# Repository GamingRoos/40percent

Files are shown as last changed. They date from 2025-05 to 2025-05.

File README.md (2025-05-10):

# THIS IS A WORK IN PROGRESS

I'm designing a 40% keyboard just for the fun of it and to learn how to make everything from scratch.  

There should be every required file in Git Repository for you to build your own, I'll also include the bill of materials for both KiCad/JLCPCB and also DigiKey if you wish to solder it all by hand.  

Here a few of the features of the board:

> - USB-C Support (USB2.0 for easy compatibility)
> - ATMEGA32U4 Microcontroller (Easily available and ready firmware support through QMK)
> - Live keymapping through QMK/VIAL
> - Gasket Mounting (Gummy O-Ring)
> - MOSTLY screwless Design (Excluding the four to mount the daughterboard)    
I'll think of more later    

What does the board conceptually look like?  

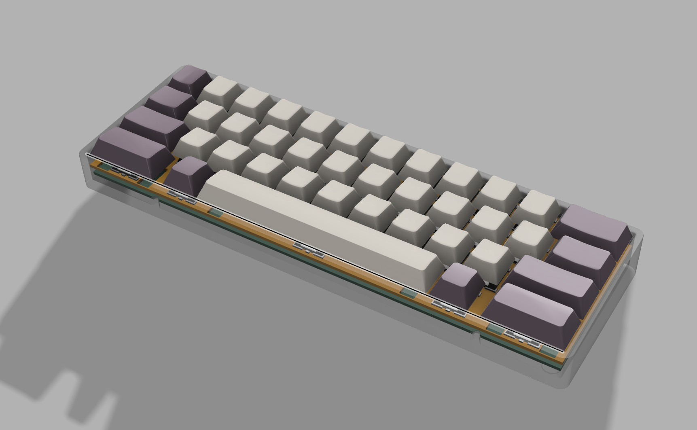
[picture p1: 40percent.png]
3D model/render of the keyboard

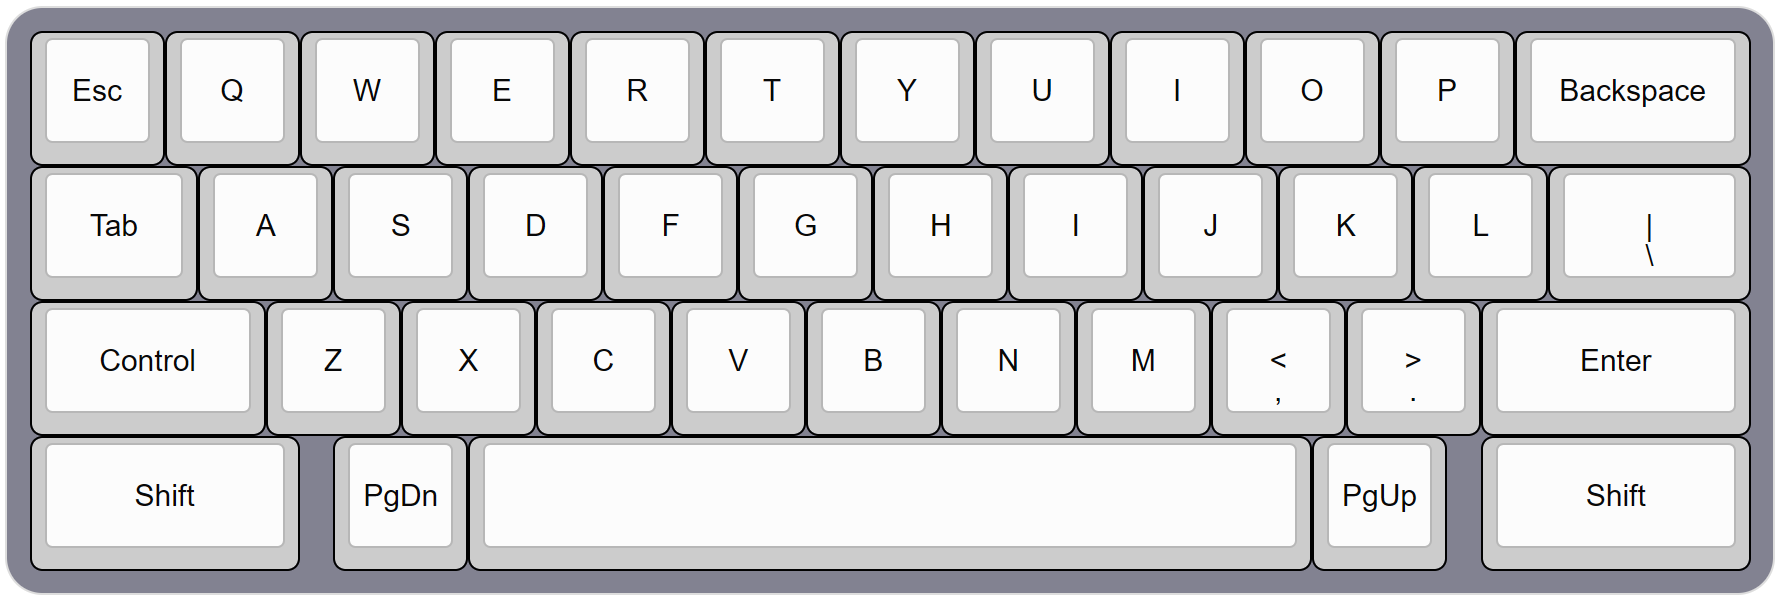
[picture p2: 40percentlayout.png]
Keyboard Layout

PgDn and PgUp will be Layer Keys  
Cool!  

> #### Bill of Materials:  
>
> ##### Main Keyboard
>
> - 1 ATMEGA32U4-AUR [DigiKey](https://www.digikey.com.au/en/products/detail/microchip-technology/ATMEGA32U4-AUR/2238241)
> - 1 FA238 16.0000MB-C3 [DigiKey](https://www.digikey.com.au/en/products/detail/epson/FA-238-16-0000MB-C3/2403378)
> - 2 22pf Ceramic Capacitor 50v (0805) [DigiKey](https://www.digikey.com.au/en/products/detail/kemet/C0805C220J5GACTU/411112)
> - 1 1uf Ceramic Capacitor 16v (0805) [DigiKey](https://www.digikey.com.au/en/products/detail/yageo/CC0805KKX7R7BB105/2103103)
> - 1 4.7uf Ceramic Capacitor 25v (0805) [DigiKey](https://www.digikey.com.au/en/products/detail/murata-electronics/GRM219R61E475KA73D/4905426)
> - 2 10K Resistor 5% 1/8W(0805) [DigiKey](https://www.digikey.com.au/en/products/detail/stackpole-electronics-inc/RMCF0805JT10K0/1757762)
> - 1 TL3342F160QG/TR Switch [DigiKey](https://www.digikey.com.au/en/products/detail/e-switch/TL3342F160QG-TR/379003)    
> - 2 SM04B-SRSS-TB JST SH1.0 4Pin Connector [DigiKey](https://www.digikey.com.au/en/products/detail/jst-sales-america-inc/SM04B-SRSS-TB/926710)
> - 1 JST SH1.0 Male/Male Cable (Size not known just yet, also to connect both PCBs)
> - 40 1N4148W/SOD-123 Diodes (0603) [DigiKey](https://www.digikey.com.au/en/products/detail/smc-diode-solutions/1N4148W/6022450)
> - 1 Printed 40percent Case
> - 40 Gateron Hotswap Sockets (Can't find on Digikey, AliExpress?) 
> - 40 MX Compatible Switches (Outemu might not work in the sockets)
> - 1 Suitable Keycap Set
> - 3 2u Plate Mount Stabiliser
> - 1 6.25u Plate Mount Stabiliser
> - 4 8mm Rubber Bump-ons for the feet
> - This MIGHT be a working O-Ring size? I'll have to find out when I make this. [oリング](https://xn--o-7eu7hjb.com/?pid=81334721)
> ##### USB-C Daughter Board
> - 1 USB4105-GF-A-060 USB-C 16pin [DigiKey](https://www.digikey.com.au/en/products/detail/gct/USB4105-GF-A-060/14559036)
> - 2 5.1k Resistor 5% 1/8W (0805) [DigiKey](https://www.digikey.com.au/en/products/detail/yageo/RC0805JR-075K1L/728338)
> - 4 M2 4mm Bolts (Screw straight into posts, if you for some reason chose to mill the case, tap it out... it's at 1.6mm ID)
> - One of the JST connectors from above
> - 1 USB-C to USB-C\A cable
> ### I'd recommend ordering a few more than you need at minimum, just incase you fuck it up. Better safe than sorry. Also, cut down on shipping cost :) Plus 5 PCB minimum from JLCPCB, five chances?

# That's pretty much it so far!

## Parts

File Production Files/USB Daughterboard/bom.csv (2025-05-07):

Designator | Footprint | Quantity | Value | LCSC Part #
J1 | USB_C_Receptacle_GCT_USB4105-xx-A_16P_TopMnt_Horizontal | 1 | USB_C_Receptacle_USB2.0_14P
J2 | JST_SH_BM04B-SRSS-TB_1x04-1MP_P1.00mm_Vertical | 1 | Conn_01x04_Pin
R1, R2 | 0805 | 2 | 5.1k

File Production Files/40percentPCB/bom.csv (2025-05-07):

Designator | Footprint | Quantity | Value | LCSC Part #
C1, C2 | 0805 | 2 | 22p
C3, C4, C5, C6 | 0805 | 4 | 0.1u
C7 | 0805 | 1 | 4.7u
C8 | 0805 | 1 | 1u
D1, D10, D11, D12, D13, D14, D15, D16, D17, D18, D19, D2, D20, D21, D22, D23, D24, D25, D26, D27, D28, D29, D3, D30, D31, D32, D33, D34, D35, D36, D37, D38, D39, D4, D40, D5, D6, D7, D8, D9 | D_SOD-123 | 40 | D
J1 | JST_SH_BM04B-SRSS-TB_1x04-1MP_P1.00mm_Vertical | 1 | JST SH 1.0 (USB)
K1, K10, K11, K12, K13, K14, K15, K16, K17, K18, K19, K2, K20, K21, K22, K23, K24, K25, K26, K27, K28, K29, K3, K30, K31, K32, K33, K34, K35, K36, K37, K38, K39, K4, K40, K5, K6, K7, K8, K9 | SW_Hotswap_Kailh_MX | 40 | KEYSW
R1, R2 | 0805 | 2 | 10K
SW1 | SW_SPST_TL3342 | 1 | SW_PUSH
U1 | TQFP-44_10x10mm_P0.8mm | 1 | ATMEGA32U4
X1 | Crystal_SMD_SeikoEpson_FA238-4pin_3.2x2.5mm_HandSoldering | 1 | XTAL_GND

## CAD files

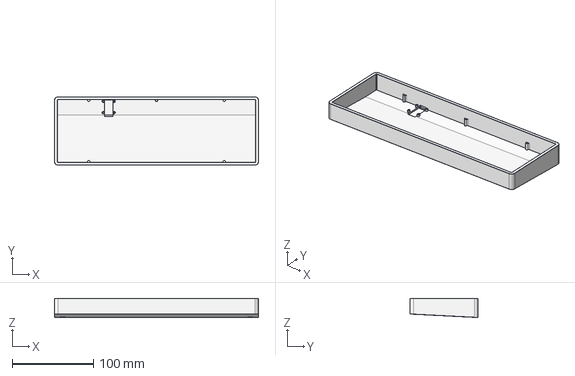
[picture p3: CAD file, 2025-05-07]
Case/40percent_case.step
250.9 x 84.2 x 23.5 mm

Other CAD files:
Case/40percent_case.stl

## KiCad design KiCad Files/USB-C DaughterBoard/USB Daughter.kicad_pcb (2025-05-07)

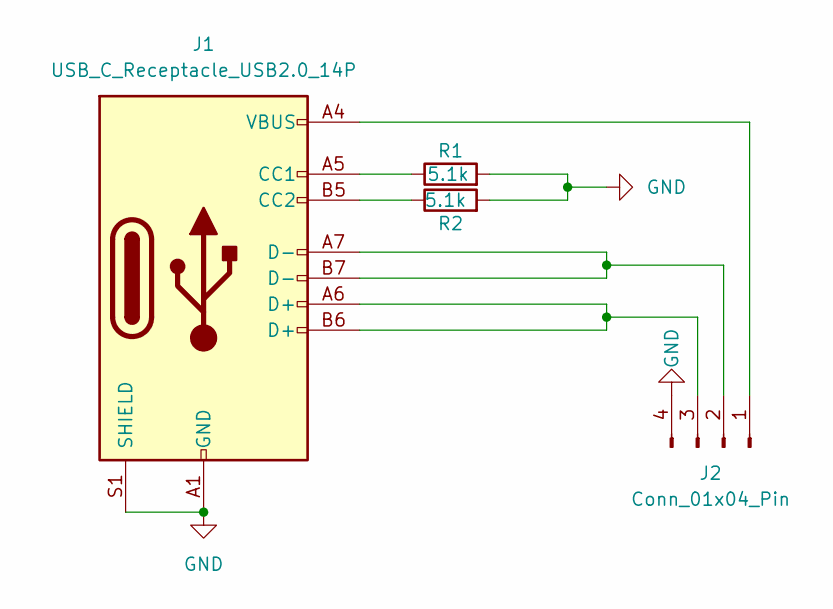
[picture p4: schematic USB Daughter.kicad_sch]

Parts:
J1: USB_C_Receptacle_USB2.0_14P; USB_C_Receptacle_GCT_USB4105-xx-A_16P_TopMnt_Horizontal
J2: Conn_01x04_Pin; JST_SH_BM04B-SRSS-TB_1x04-1MP_P1.00mm_Vertical
R1, R2: 5.1k; C_0805_2012Metric_Pad1.18x1.45mm_HandSolder

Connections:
GND: J1.A1 (GND), J1.A12 (GND), J1.B1 (GND), J1.B12 (GND), J1.S1 (SHIELD), J2.4, R1.2, R2.2
unnamed: J1.A5 (CC1), R1.1
unnamed: J1.B5 (CC2), R2.1
unnamed: J1.A4 (VBUS), J1.A9 (VBUS), J1.B4 (VBUS), J1.B9 (VBUS), J2.1
unnamed: J1.A7 (D-), J1.B7 (D-), J2.2
unnamed: J1.A6 (D+), J1.B6 (D+), J2.3

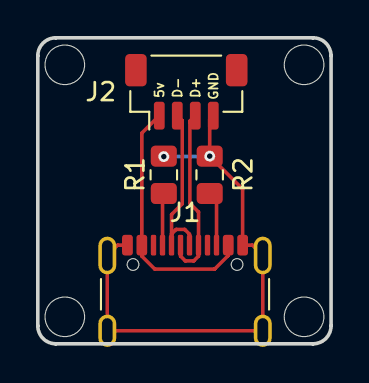
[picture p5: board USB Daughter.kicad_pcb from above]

Board: 2 copper layers, 16.3 x 17.0 mm, 4 parts (0 on the bottom side), 6 nets.

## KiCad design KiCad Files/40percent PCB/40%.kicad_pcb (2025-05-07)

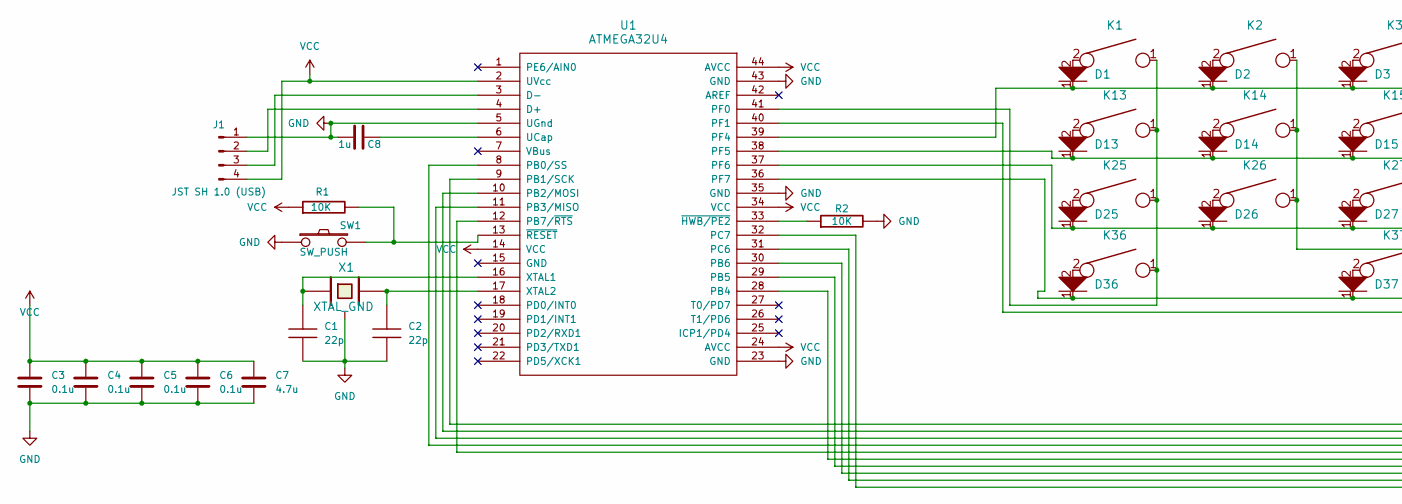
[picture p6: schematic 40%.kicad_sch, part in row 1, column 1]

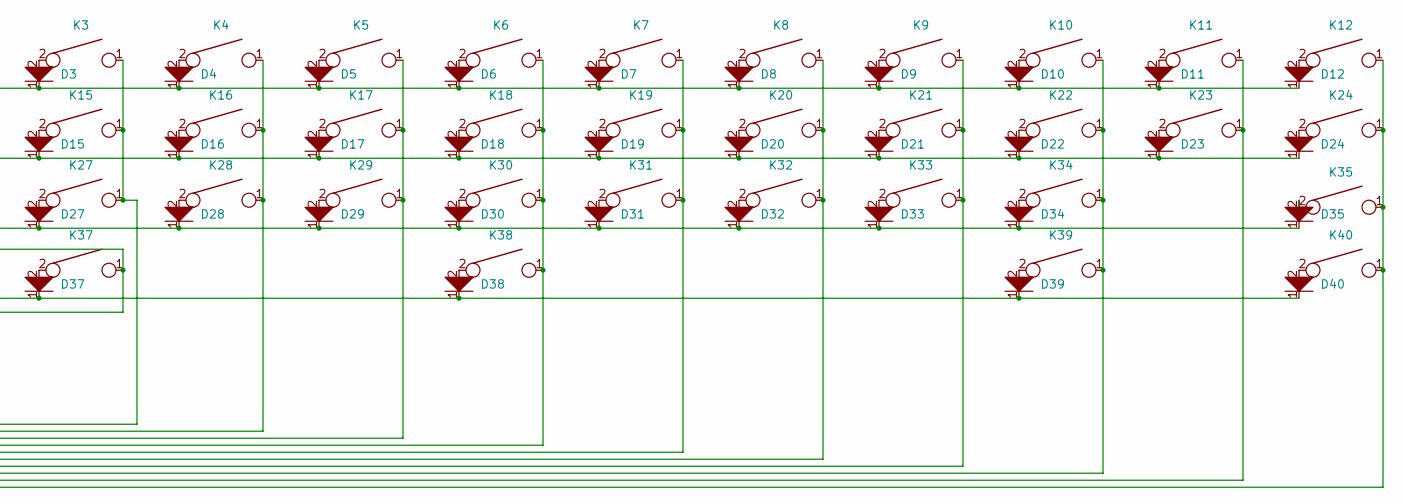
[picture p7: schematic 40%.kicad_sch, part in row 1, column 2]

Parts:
C1, C2: 22p; C_0805_2012Metric
C3, C4, C5, C6: 0.1u; C_0805_2012Metric
C7: 4.7u; C_0805_2012Metric
C8: 1u; C_0805_2012Metric
D1, D2, D3, D4, D5, D6, D7, D8, D9, D10, D11, D12, D13, D14, D15, D16, D17, D18, D19, D20, D21, D22, D23, D24, D25, D26, D27, D28, D29, D30, D31, D32, D33, D34, D35, D36, D37, D38, D39, D40: D; D_SOD-123
J1: JST SH 1.0 (USB); JST_SH_BM04B-SRSS-TB_1x04-1MP_P1.00mm_Vertical
K1, K2, K3, K4, K5, K6, K7, K8, K9, K10, K11, K12, K13, K14, K15, K16, K17, K18, K19, K20, K21, K22, K23, K24, K25, K26, K27, K28, K29, K30, K31, K32, K33, K34, K35, K36, K37, K38, K39, K40: KEYSW; SW_Hotswap_Kailh_MX
R1, R2: 10K; R_0805_2012Metric_Pad1.20x1.40mm_HandSolder
SW1: SW_PUSH; SW_SPST_TL3342
U1: ATMEGA32U4; TQFP-44_10x10mm_P0.8mm
X1: XTAL_GND; Crystal_SMD_SeikoEpson_FA238-4pin_3.2x2.5mm_HandSoldering

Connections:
unnamed: D1.2, K1.2
unnamed: D2.2, K2.2
unnamed: D3.2, K3.2
unnamed: D4.2, K4.2
unnamed: D5.2, K5.2
unnamed: D6.2, K6.2
unnamed: D7.2, K7.2
unnamed: D8.2, K8.2
unnamed: D9.2, K9.2
unnamed: D10.2, K10.2
unnamed: D11.2, K11.2
unnamed: D12.2, K12.2
unnamed: D13.2, K13.2
unnamed: D14.2, K14.2
unnamed: D15.2, K15.2
unnamed: D16.2, K16.2
unnamed: D17.2, K17.2
unnamed: D18.2, K18.2
unnamed: D19.2, K19.2
unnamed: D20.2, K20.2
unnamed: D21.2, K21.2
unnamed: D22.2, K22.2
unnamed: D23.2, K23.2
unnamed: D24.2, K24.2
unnamed: D25.2, K25.2
unnamed: D26.2, K26.2
unnamed: D27.2, K27.2
unnamed: D28.2, K28.2
unnamed: D29.2, K29.2
unnamed: D30.2, K30.2
unnamed: D31.2, K31.2
unnamed: D32.2, K32.2
unnamed: D33.2, K33.2
unnamed: D34.2, K34.2
unnamed: D35.2, K35.2
unnamed: D36.2, K36.2
unnamed: D37.2, K37.2
unnamed: D38.2, K38.2
unnamed: D39.2, K39.2
unnamed: D40.2, K40.2
unnamed: J1.2 (Pin_3), U1.4 (D+)
unnamed: J1.3 (Pin_2), U1.3 (D-)
unnamed: K6.1, K18.1, K30.1, K38.1, U1.8 (PB0/SS)
unnamed: K3.1, K15.1, K27.1, U1.9 (PB1/SCK)
unnamed: K4.1, K16.1, K28.1, U1.10 (PB2/MOSI)
unnamed: K5.1, K17.1, K29.1, U1.11 (PB3/MISO)
unnamed: K8.1, K20.1, K32.1, U1.28 (PB4)
unnamed: K9.1, K21.1, K33.1, U1.29 (PB5)
unnamed: K10.1, K22.1, K34.1, K39.1, U1.30 (PB6)
unnamed: K7.1, K19.1, K31.1, U1.12 (PB7/~RTS)
unnamed: K11.1, K23.1, U1.31 (PC6)
unnamed: K12.1, K24.1, K35.1, K40.1, U1.32 (PC7)
unnamed: K1.1, K13.1, K25.1, K36.1, U1.41 (PF0)
unnamed: K2.1, K14.1, K26.1, K37.1, U1.40 (PF1)
unnamed: D1.1, D2.1, D3.1, D4.1, D5.1, D6.1, D7.1, D8.1, D9.1, D10.1, D11.1, D12.1, U1.39 (PF4)
unnamed: D13.1, D14.1, D15.1, D16.1, D17.1, D18.1, D19.1, D20.1, D21.1, D22.1, D23.1, D24.1, U1.38 (PF5)
unnamed: D25.1, D26.1, D27.1, D28.1, D29.1, D30.1, D31.1, D32.1, D33.1, D34.1, D35.1, U1.37 (PF6)
unnamed: D36.1, D37.1, D38.1, D39.1, D40.1, U1.36 (PF7)
unnamed: C8.1, U1.6 (UCap)
unnamed: C1.1, U1.16 (XTAL1), X1.1
unnamed: R2.1, U1.33 (~HWB/PE2)
unnamed: R1.2, SW1.2, U1.13 (~RESET)

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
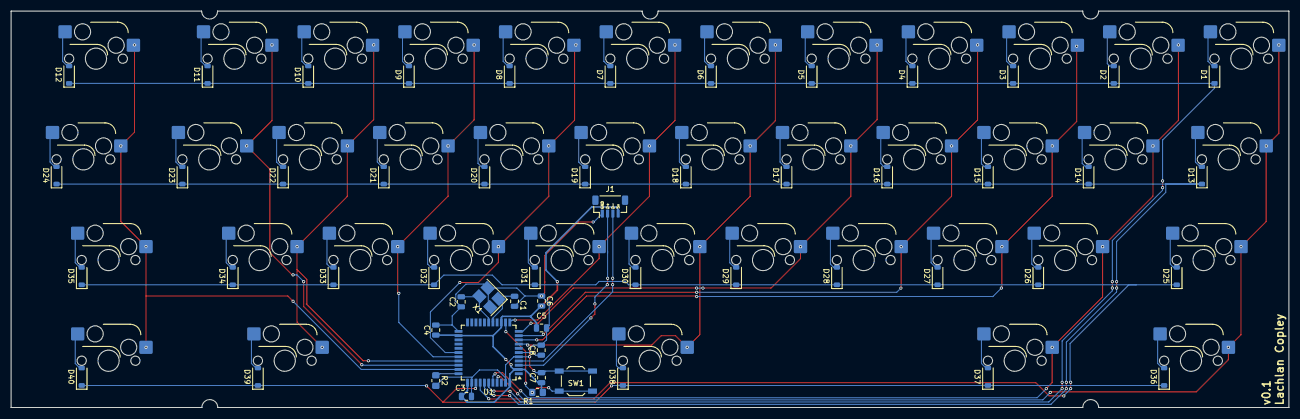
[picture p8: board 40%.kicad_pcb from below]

Board: 2 copper layers, 241.8 x 75.0 mm, 94 parts (54 on the bottom side), 65 nets.
